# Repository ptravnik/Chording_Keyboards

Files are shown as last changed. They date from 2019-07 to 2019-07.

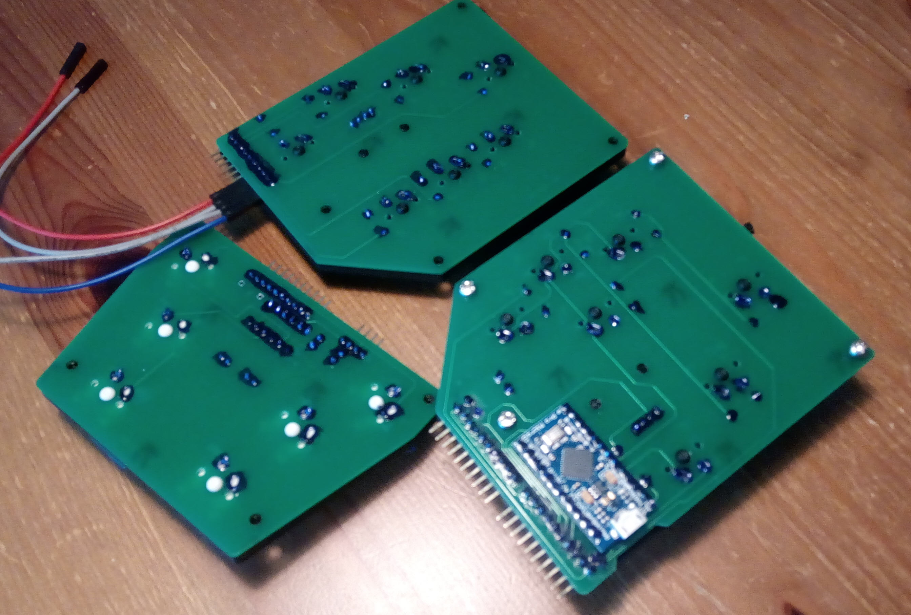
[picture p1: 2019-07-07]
Pictures/04_Soldering_Completed.jpg

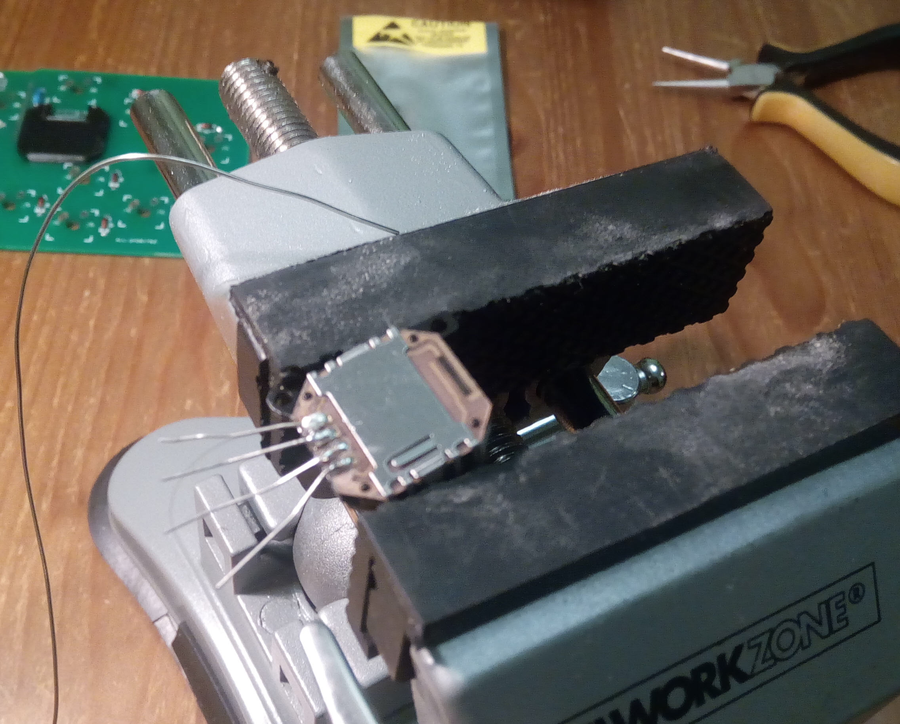
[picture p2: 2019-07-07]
Pictures/03_Soldering_PSP_Joystick.jpg

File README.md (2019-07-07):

This project contains files for K-Chord and other chording keyboards.

[1] Why chording?
Medics may disagree, but it seems that constantly bending fingers back and forth while touch-typing by the 10-finger method is the second reason (besides the poor posture) why people have carpal tunnel syndrome. In such sense, "ergonomic" keyboards help just a little if not at all. There are numerous mechanical keyboard on the market. Cherry switches and their clones offer performance superior to the film keyboards, but the idea is pretty much the same: 10 fingers, 60 or so switches; once in a while one must reach that switch in the galaxy far, far away with the left or right pinky!

The main drive for this project was not to type faster than speech, a a steno professionals do, but to type at reasonable speed whole day with no strain. In practice, I seldom exceed 20 WPM (just cannot think GOOD code that fast!), but can maintain this for many hours - without ever bending a finger. The keyboard has 8 finger buttons and 6 thumb buttons. The fingers always remain in the "home" position; there is nothing else, but the home position. The thumbs move as the nature intended: in the main (grip) joint, with the zero second joint bending. By shifting the fingers down 1 inch, a set of two analog joysticks, three mouse buttons and 4 arrow keys is accessible. Together with the left thumb, the arrow keys provide full set of cursor movements, including page-up and page-down.

This is the third version of my chording keyboard. The work in progress is described on the Hackaday site https://hackaday.io/project/25386-chording-hybrid-keyboard. The experience has been good so far. I use it now as my primary input method, for text writing, programming, and operating specialized software.

[2] Building a chording keyboard.
This project depository contains:

(a) the full electronics description as a set of three PCBs,

(b) A set of CNC files for making a body, and

(c) the code for Arduino Micro, which drives the entire project. No modification is required at the operating system side; the keyboard works as an off-the-shelf USB keyboard. It has been tested on Windows and Linux extensively.

To order PCBs, simply use Gerber files provided or modify KiCAD files to you liking. The body can be machined on a CNC router (recommeneded), 3-D printed or laser-cut (some compromizes on the shape). To build the firmware, copy the .ino folder and use Arduino IDE to compile and upload (put any macros of your liking into the macros.h file).

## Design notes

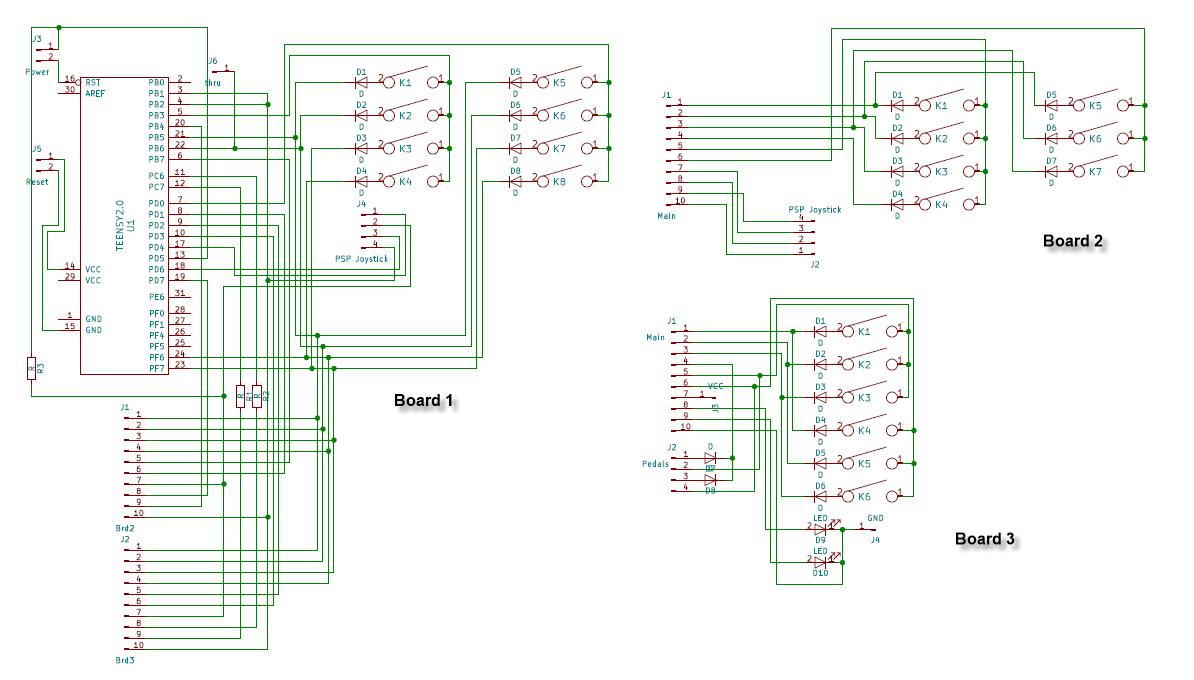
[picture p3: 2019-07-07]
Pictures/Schematics.png

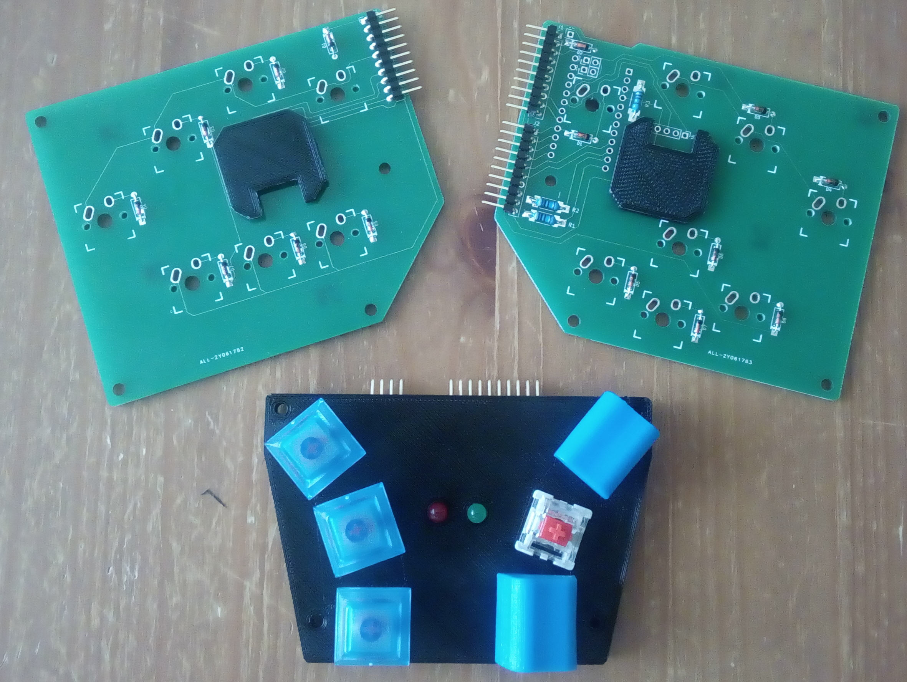
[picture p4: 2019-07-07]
Pictures/02_Stands_for_Joysticks.jpg

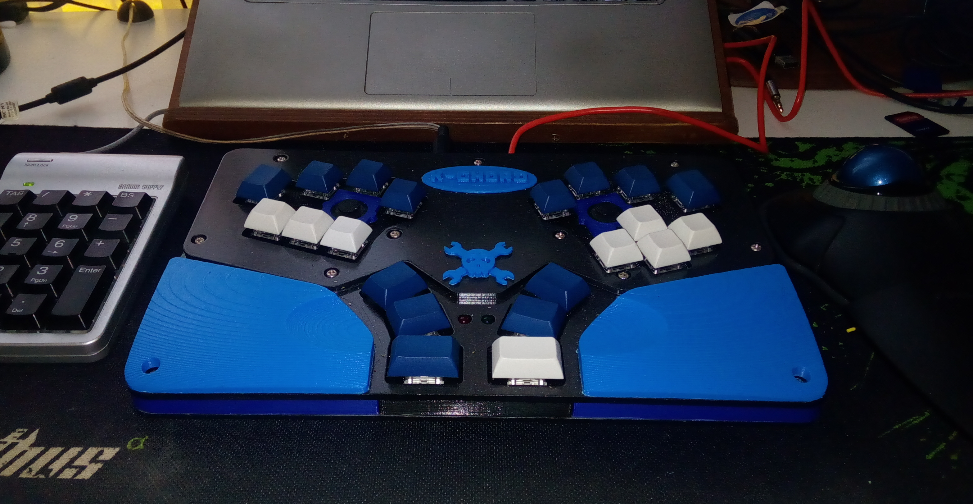
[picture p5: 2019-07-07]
Pictures/08_Keyboard_Completed.jpg

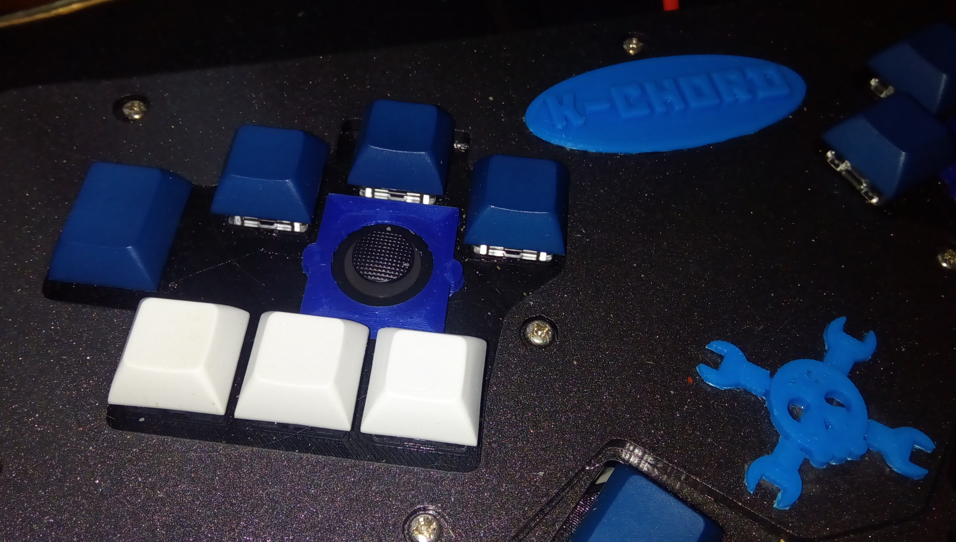
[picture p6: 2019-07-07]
Pictures/09_Left_Hand.jpg

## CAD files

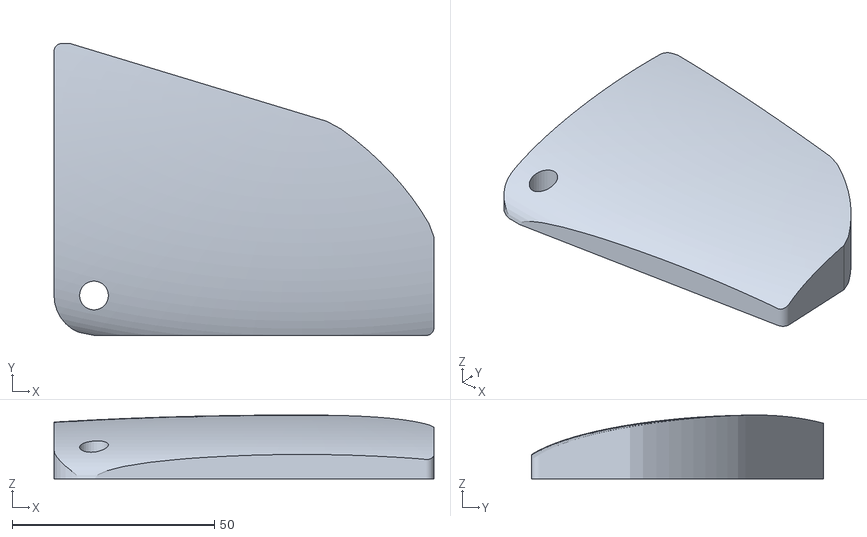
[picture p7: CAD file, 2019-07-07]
stls/Wrist_L.stl
94.1 x 72.3 x 15.8

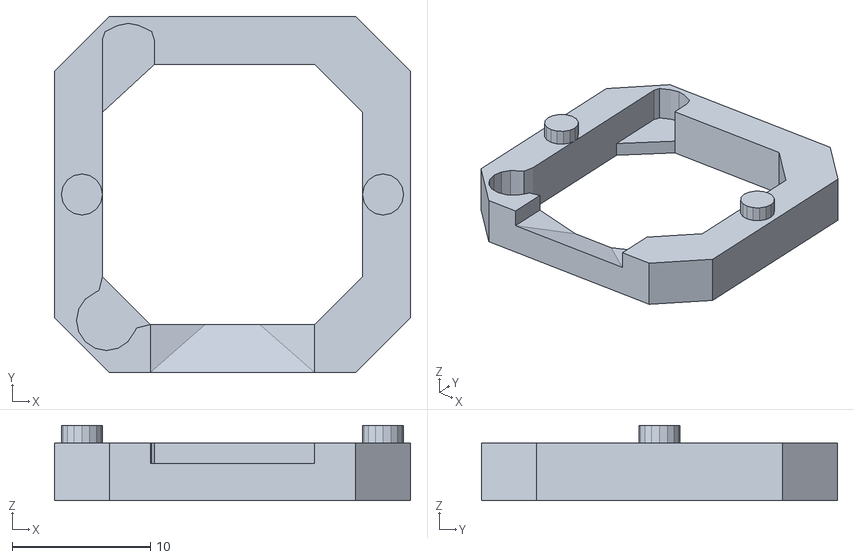
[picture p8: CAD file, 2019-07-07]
stls/Joystick_Holder.stl
25.7 x 25.7 x 5.45

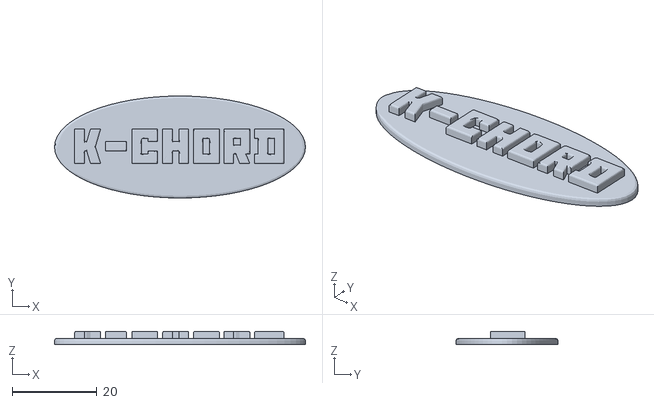
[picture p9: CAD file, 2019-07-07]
stls/K_Chord_Logo.stl
59.4 x 24.1 x 3.17

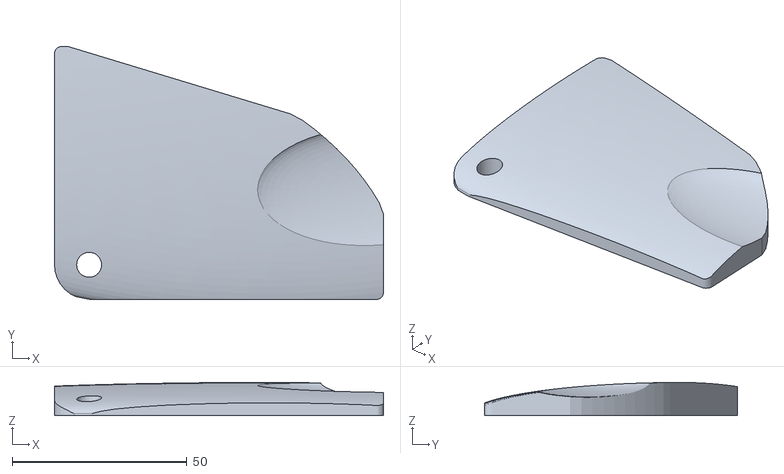
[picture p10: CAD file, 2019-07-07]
stls/Wrist_L_Low.stl
94.1 x 72.3 x 9.49

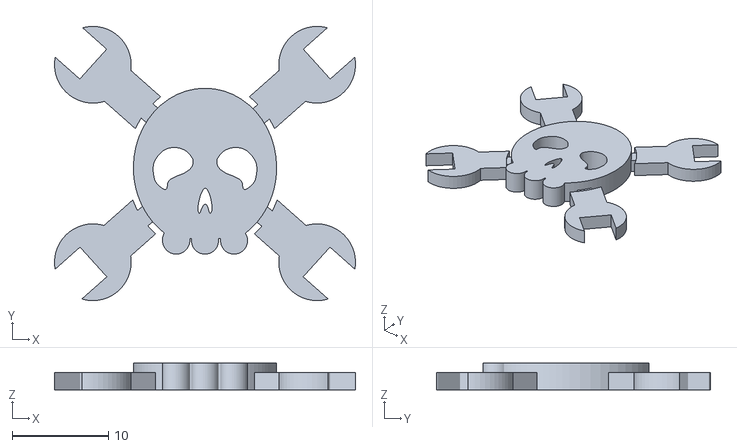
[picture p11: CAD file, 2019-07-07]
stls/Hackaday_Logo.stl
31.3 x 28.5 x 2.77

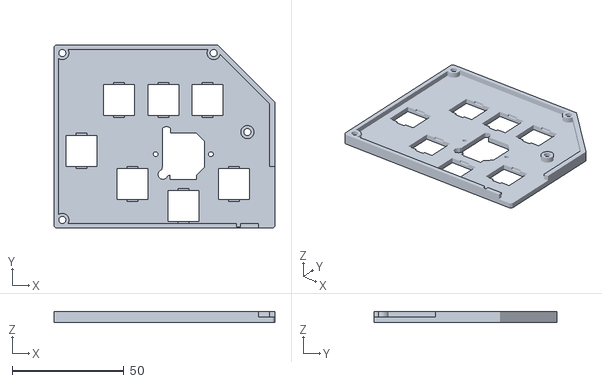
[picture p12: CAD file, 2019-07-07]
stls/Sabot_2.stl
99.0 x 82.2 x 4.95

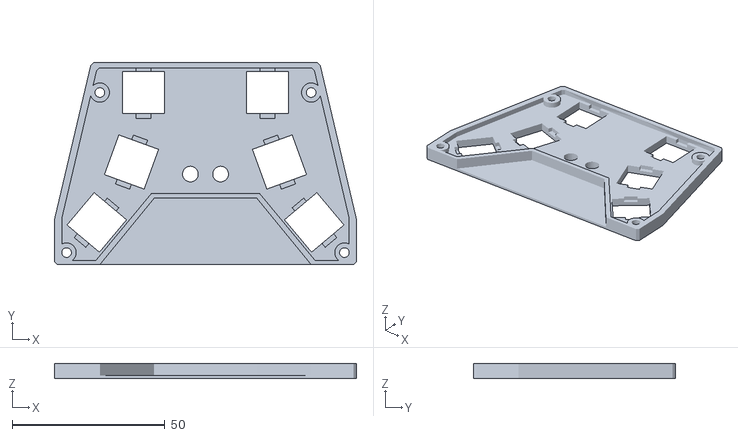
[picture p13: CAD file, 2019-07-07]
stls/Sabot_3.stl
99.0 x 66.3 x 4.95

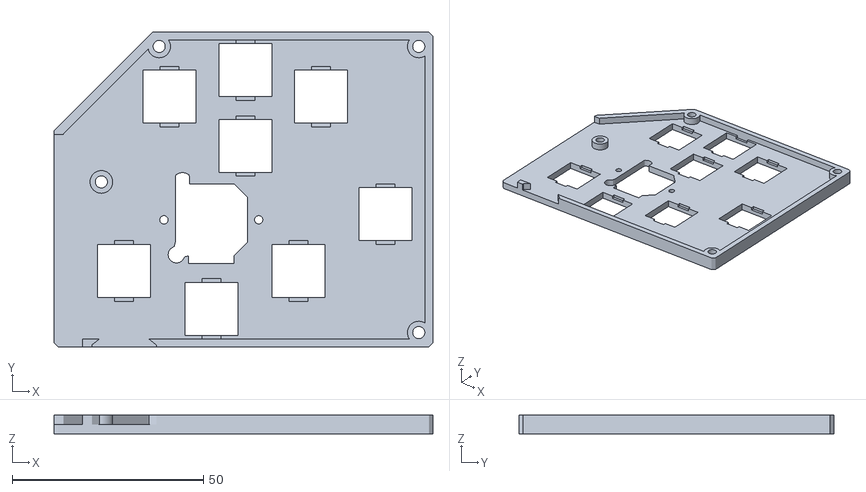
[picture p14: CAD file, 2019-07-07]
stls/Sabot_1.stl
99.0 x 82.2 x 4.95

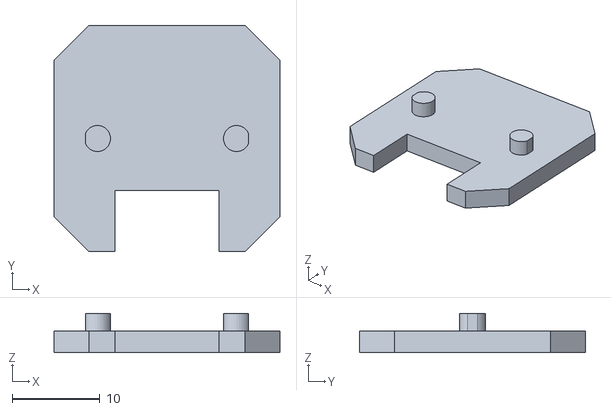
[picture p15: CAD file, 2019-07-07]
stls/Joystick_Stand.stl
25.7 x 25.7 x 4.46

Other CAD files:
stls/Wrist_R_Low.stl
stls/Wrist_R.stl

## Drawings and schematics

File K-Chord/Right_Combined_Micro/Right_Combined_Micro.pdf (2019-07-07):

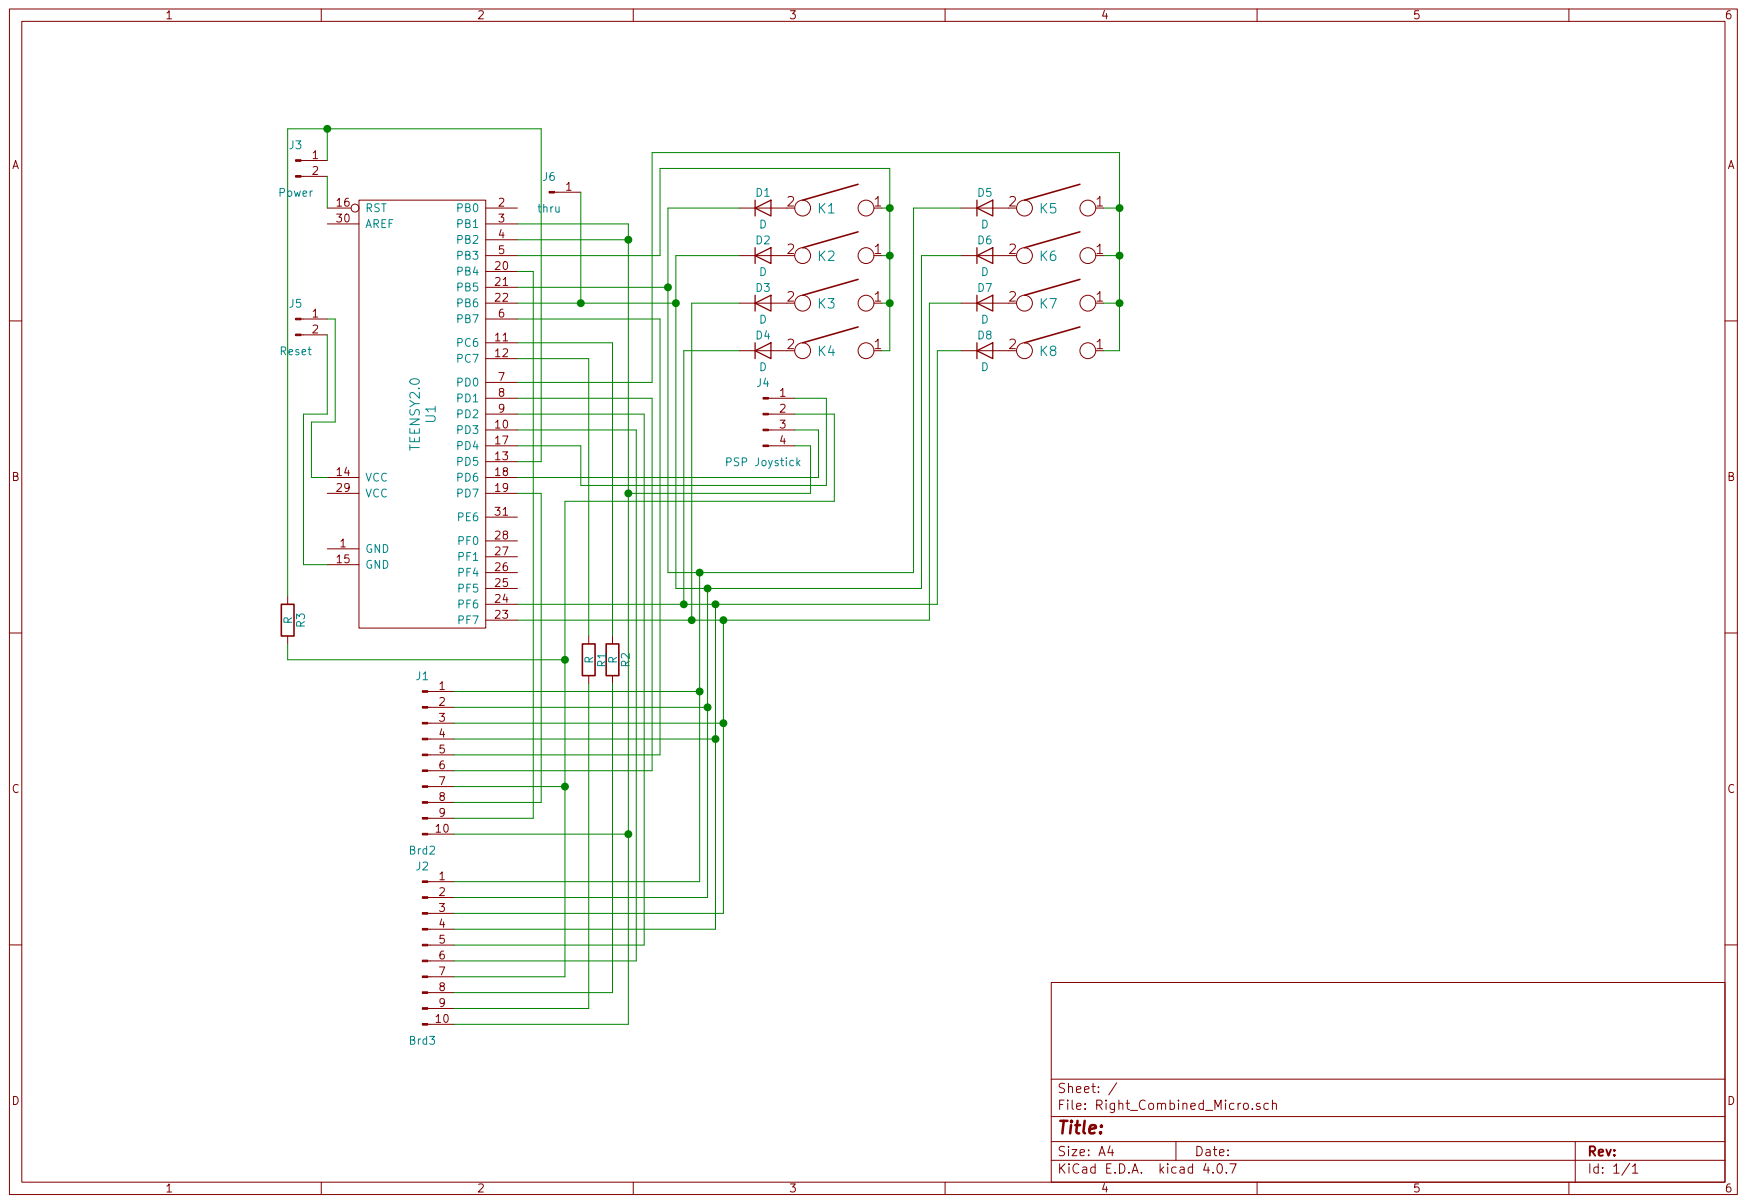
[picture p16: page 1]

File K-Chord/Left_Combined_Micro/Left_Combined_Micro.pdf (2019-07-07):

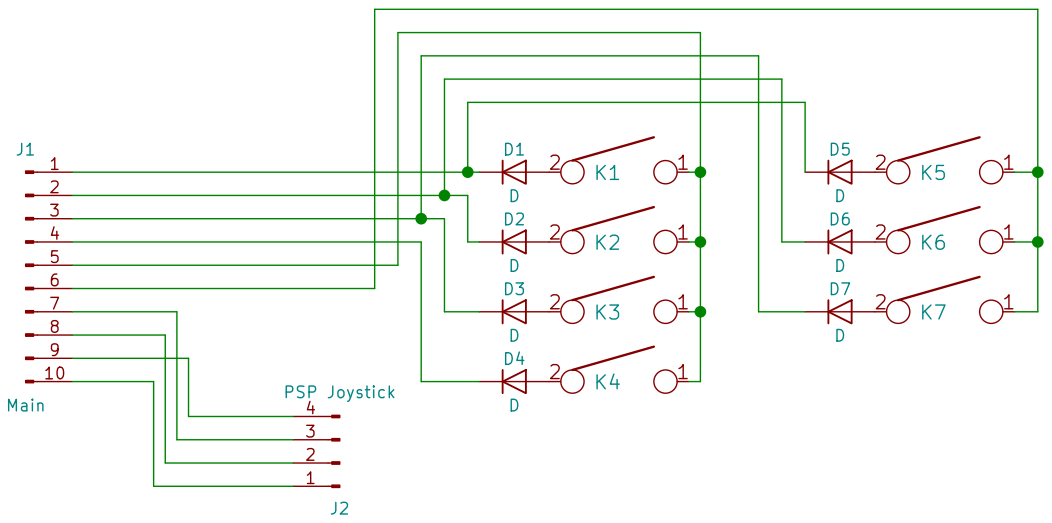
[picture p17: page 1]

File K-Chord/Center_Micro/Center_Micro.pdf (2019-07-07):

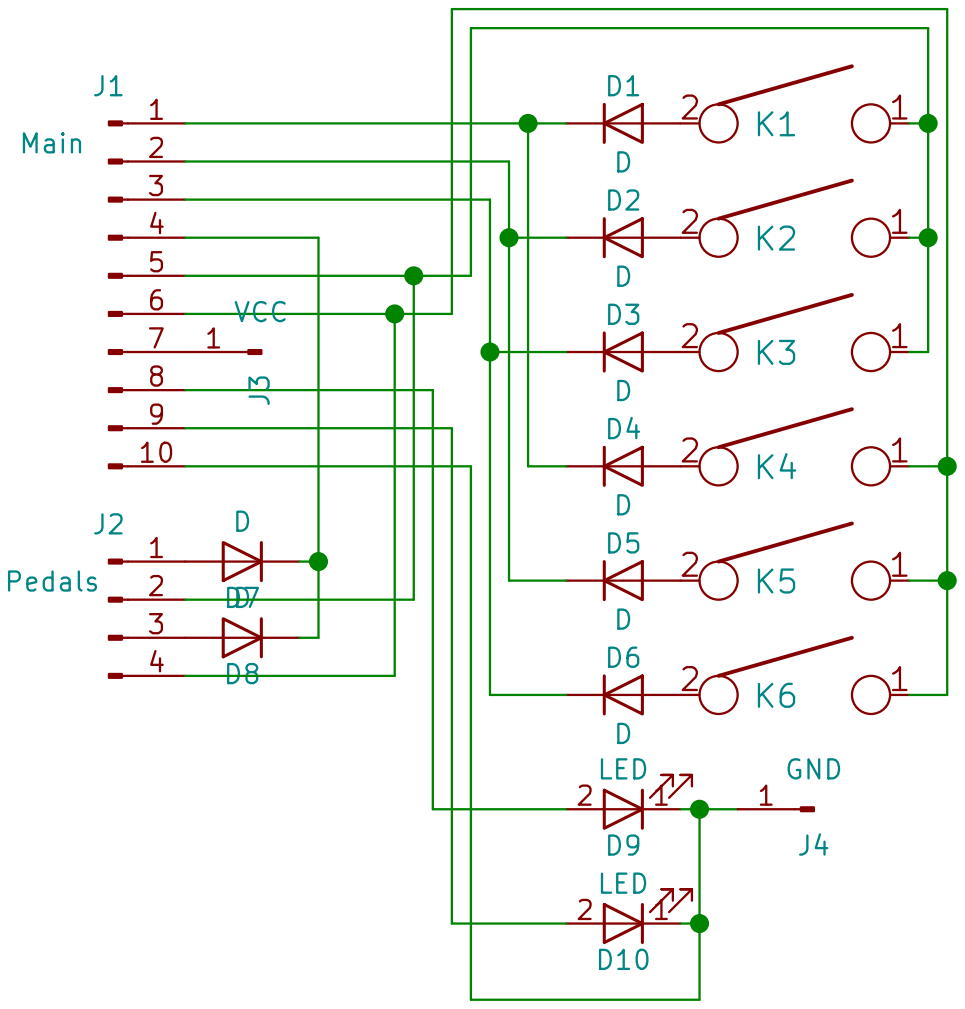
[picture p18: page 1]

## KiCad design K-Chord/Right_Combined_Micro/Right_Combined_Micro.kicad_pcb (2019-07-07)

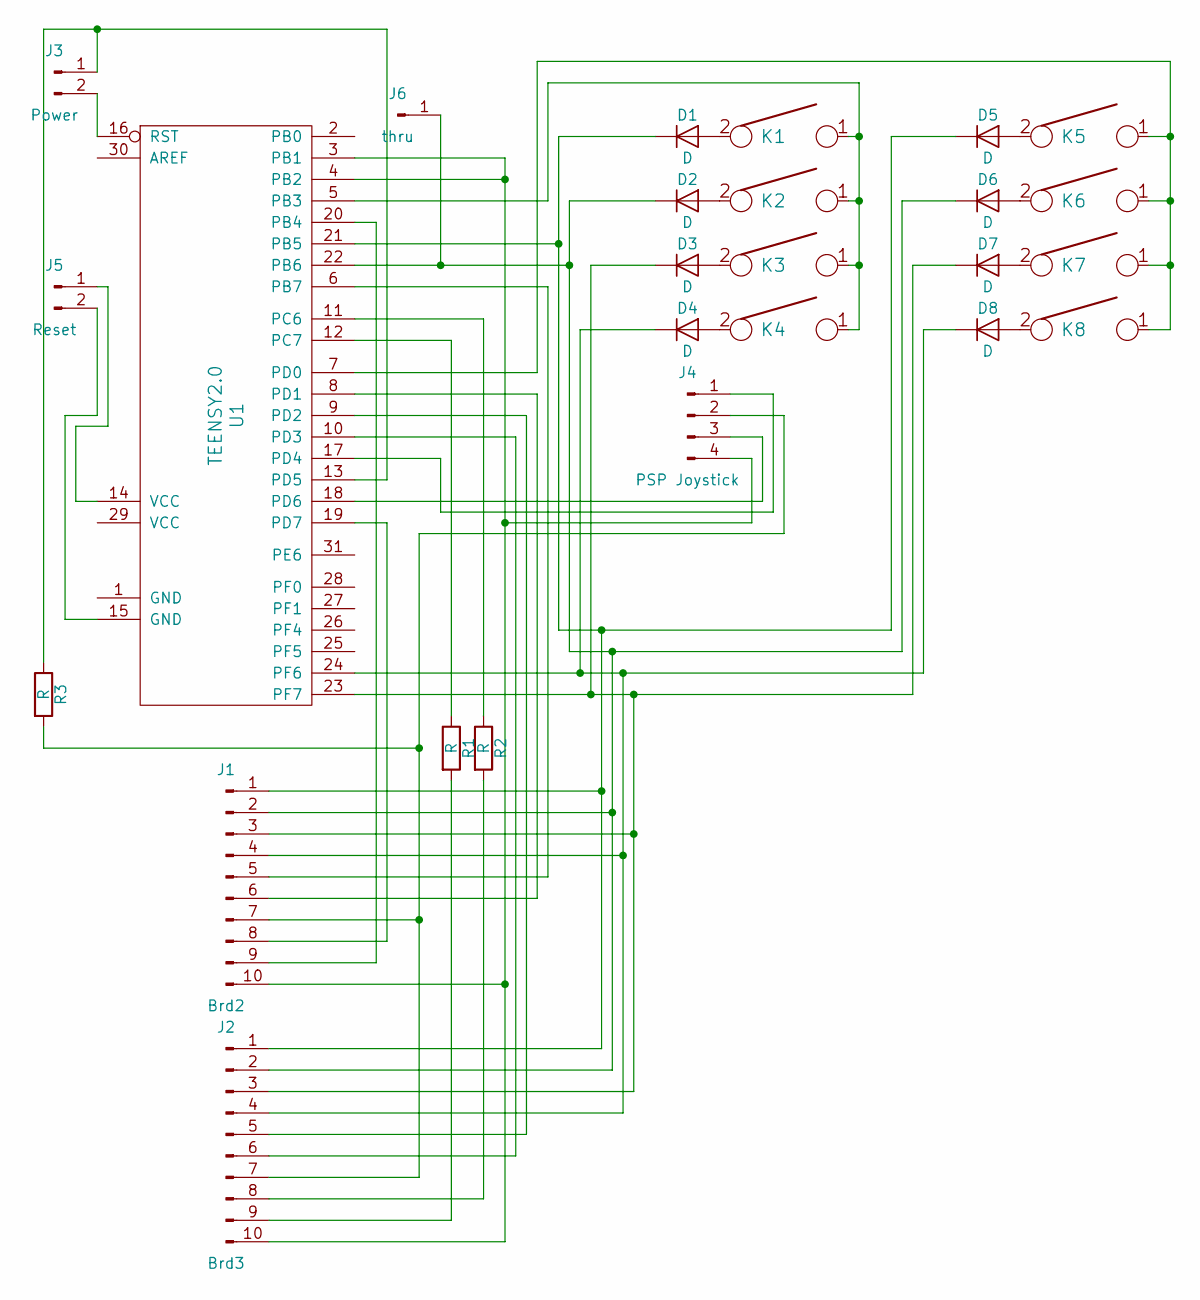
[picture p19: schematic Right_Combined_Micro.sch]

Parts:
D1, D2, D3, D4, D5, D6, D7, D8: D; D_SOD123_axial
J1: Brd2; Pin_Header_Straight_1x10_Pitch2.54mm
J2: Brd3; Pin_Header_Straight_1x10_Pitch2.54mm
J3: Power; Pin_Header_Straight_1x02_Pitch2.54mm
J4: PSP Joystick; Pin_Header_Straight_1x04_Pitch2.54mm
J5: Reset; Pin_Header_Straight_1x02_Pitch2.54mm
J6: thru; Pin_Header_Straight_1x01_Pitch2.54mm
K1, K2, K3, K4, K5, K6, K7, K8: KEYSW; Mx_Alps_100
R1, R2, R3: R; Resistor_SMD+THTuniversal_2512_RM10_HandSoldering
U1: TEENSY2.0; Pro_Micro

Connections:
unnamed: D1.1 (K), D5.1 (K), J1.1, J2.1, U1.21 (PB5)
unnamed: D1.2 (A), K1.2
unnamed: D2.1 (K), D6.1 (K), J1.2, J2.2, J6.1, U1.22 (PB6)
unnamed: D2.2 (A), K2.2
unnamed: D3.1 (K), D7.1 (K), J1.3, J2.3, U1.23 (PF7)
unnamed: D3.2 (A), K3.2
unnamed: D4.1 (K), D8.1 (K), J1.4, J2.4, U1.24 (PF6)
unnamed: D4.2 (A), K4.2
unnamed: D5.2 (A), K5.2
unnamed: D6.2 (A), K6.2
unnamed: D7.2 (A), K7.2
unnamed: D8.2 (A), K8.2
unnamed: J1.5, U1.6 (PB7)
unnamed: J1.6, U1.8 (PD1)
unnamed: J1.7, J2.7, J4.2, R3.2
unnamed: J1.8, U1.19 (PD7)
unnamed: J1.9, U1.20 (PB4)
unnamed: J1.10, J2.10, J4.4, U1.3 (PB1), U1.4 (PB2)
unnamed: J2.5, U1.9 (PD2)
unnamed: J2.6, U1.10 (PD3)
unnamed: J2.8, R2.2
unnamed: J2.9, R1.2
unnamed: J3.1, R3.1, U1.13 (PD5)
unnamed: J3.2, U1.16 (RST)
unnamed: J4.1, U1.17 (PD4)
unnamed: J4.3, U1.18 (PD6)
unnamed: J5.1, U1.14 (VCC)
unnamed: J5.2, U1.15 (GND)
unnamed: K1.1, K2.1, K3.1, K4.1, U1.5 (PB3)
unnamed: K5.1, K6.1, K7.1, K8.1, U1.7 (PD0)
unnamed: R1.1, U1.12 (PC7)
unnamed: R2.1, U1.11 (PC6)

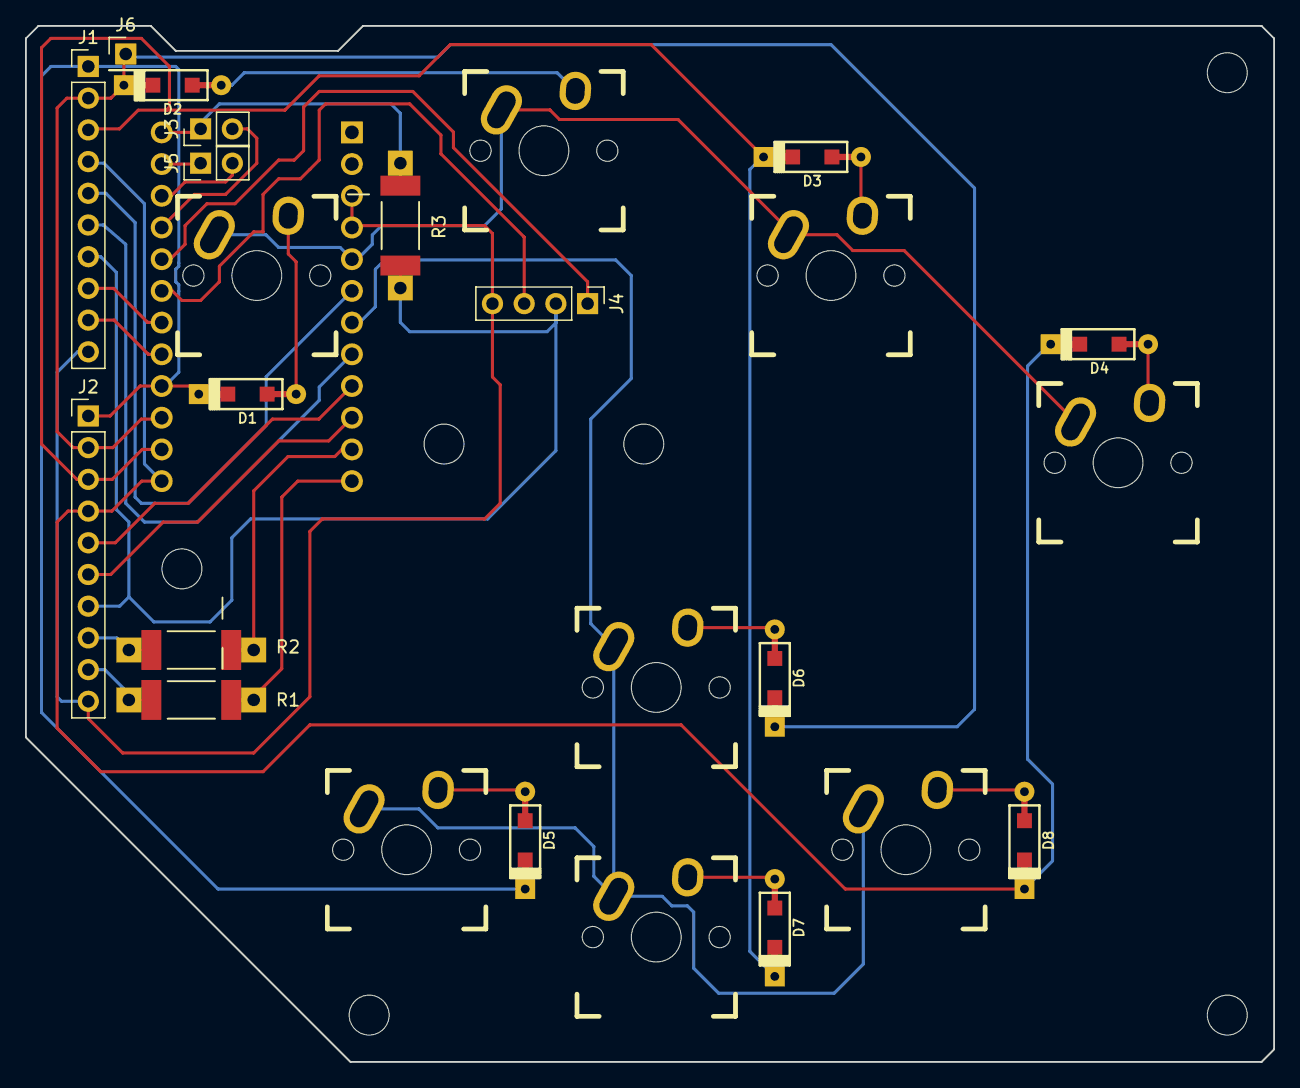
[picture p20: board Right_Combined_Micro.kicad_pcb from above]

Board: 2 copper layers, 100.0 x 83.0 mm, 26 parts (1 on the bottom side), 32 nets.

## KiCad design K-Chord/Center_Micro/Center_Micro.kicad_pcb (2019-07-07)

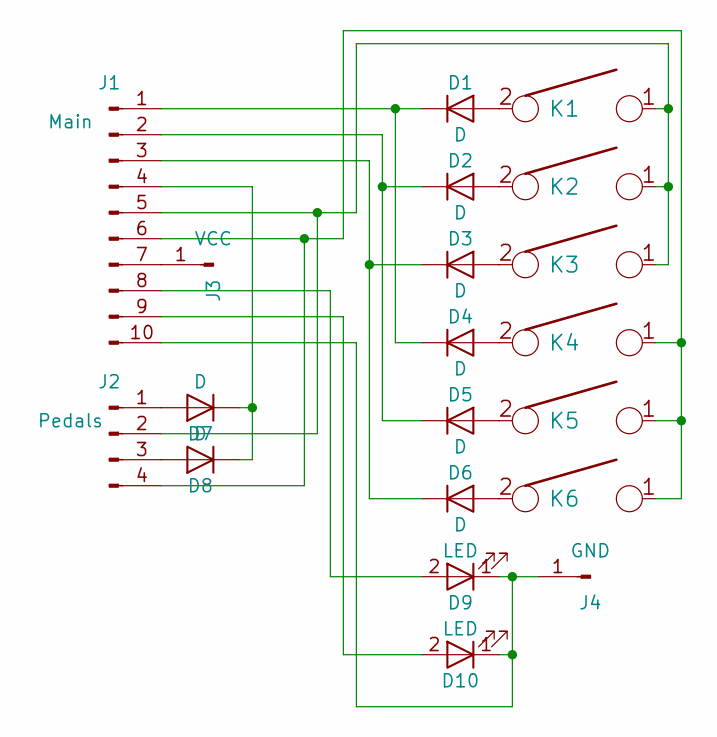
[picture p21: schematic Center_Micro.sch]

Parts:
D1, D2, D3, D4, D5, D6, D7, D8: D; D_SOD123_axial
D9, D10: LED; LED_TH
J1: Main; Pin_Header_Angled_1x10_Pitch2.54mm
J2: Pedals; Pin_Header_Angled_1x04_Pitch2.54mm
J3: VCC; Pin_Header_Straight_1x01_Pitch2.54mm
J4: GND; Pin_Header_Straight_1x01_Pitch2.54mm
K1, K2, K3, K4, K5, K6: KEYSW; Mx_Alps_100

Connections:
unnamed: D1.1 (K), D4.1 (K), J1.1
unnamed: D1.2 (A), K1.2
unnamed: D2.1 (K), D5.1 (K), J1.2
unnamed: D2.2 (A), K2.2
unnamed: D3.1 (K), D6.1 (K), J1.3
unnamed: D3.2 (A), K3.2
unnamed: D4.2 (A), K4.2
unnamed: D5.2 (A), K5.2
unnamed: D6.2 (A), K6.2
unnamed: D7.1 (K), D8.1 (K), J1.4
unnamed: D7.2 (A), J2.1
unnamed: D8.2 (A), J2.3
unnamed: D9.2 (A), J1.8
unnamed: D9.1 (K), D10.1 (K), J1.10, J4.1
unnamed: D10.2 (A), J1.9
unnamed: J1.5, J2.2, K1.1, K2.1, K3.1
unnamed: J1.6, J2.4, K4.1, K5.1, K6.1
unnamed: J1.7, J3.1

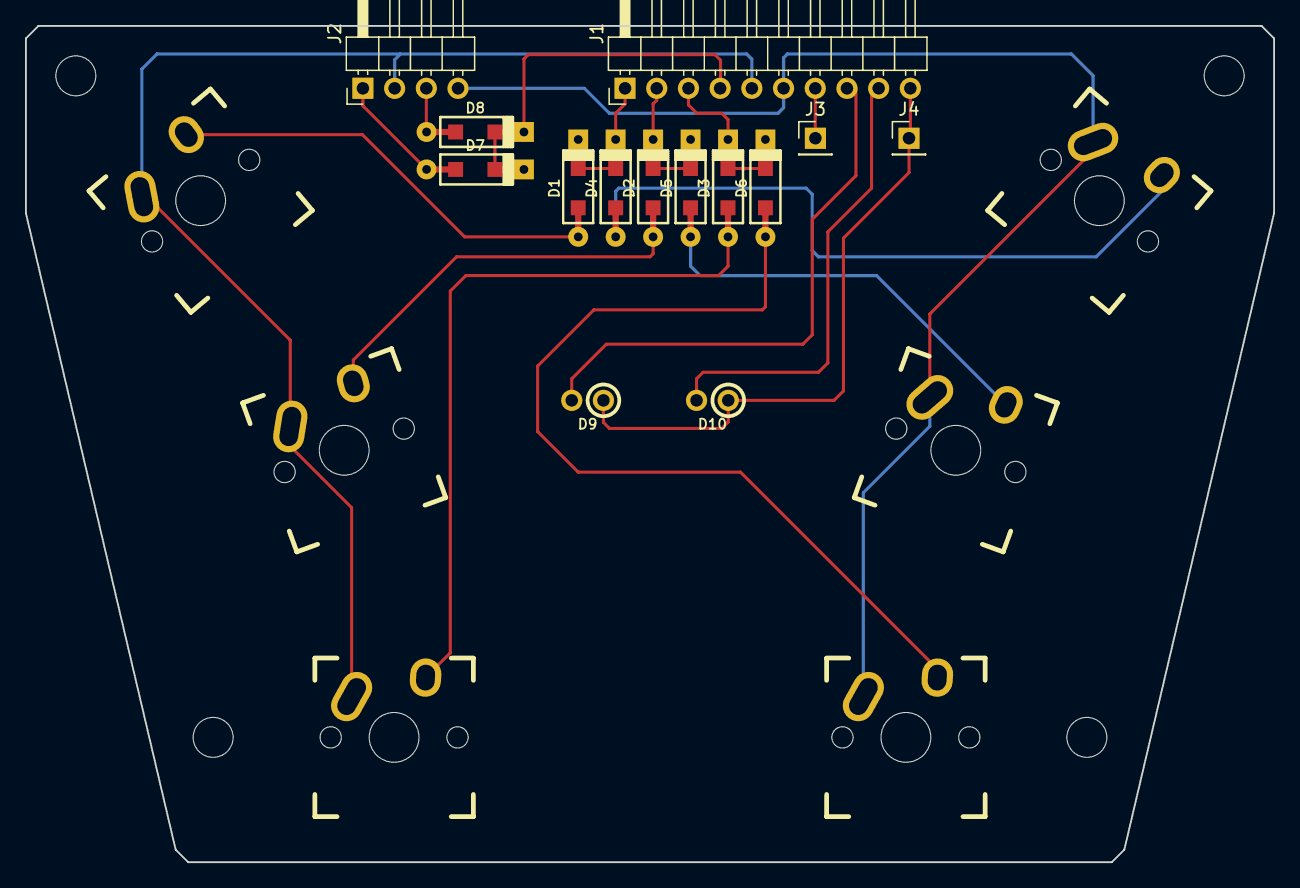
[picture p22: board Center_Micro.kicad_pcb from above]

Board: 2 copper layers, 100.0 x 67.0 mm, 20 parts (0 on the bottom side), 18 nets.

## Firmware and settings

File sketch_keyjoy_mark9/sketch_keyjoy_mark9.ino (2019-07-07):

//
// 21-button input method for stationary chorded keyboard with 2 PSP joysticks
// Left hand: 4 finger buttons and 3 mouse buttons
// Right hand: 4 finger buttons and 4 arrow buttons
// Left thumb: BACK, Shift, Control
// Right thumb: SPACE, Function, Alt
// v 9.0 04-Jul-2019
// Tested with Arduino IDE 1.8.9
// Set the board to Arduiono/Genuino Micro
// This work is public domain under GNU licence
//

// Uncomment for serial debugging
//#define _DEBUG
//#define _DEBUG_MOUSE
//#define _DEBUG_KEYBOARD

// Uncomment to disable hardware while debugging
//#define _DISABLE_MOUSE
//#define _DISABLE_KEYBOARD

#include <Keyboard.h>
#include <Mouse.h>
#include "keys.h"
#include "macros.h"
#include "keyjoy.h"

//
// Setup code here, to run once:
//
void setup()
{
  #ifdef _DEBUG
  Serial.begin(9600);
  #endif

  for ( int i = 0; i < 2; i++)
  {
    pinMode(LEDPins[i], OUTPUT);
    digitalWrite(LEDPins[i], HIGH);
  }

  Calibrate_Pots();

  for ( int i = 0; i < 4; i++)
  {
    pinMode(readPins[i], INPUT_PULLUP);
  }
  for ( int i = 0; i < 6; i++)
  {
    pinMode(writePins[i], OUTPUT);
    digitalWrite(writePins[i], HIGH);
  }

  Read_Arrow_Buttons();
  keyboardActive = (arrow_buttons[0] + arrow_buttons[1] + arrow_buttons[2] + arrow_buttons[3]) == 0;

  if ( !keyboardActive) return;
  Mouse.begin();
  Keyboard.begin();
  delay( 500);
  SetLEDs();
  return;  
}

//
// runs continuously
//
void loop()
{
  int lCombo;
  int rCombo;
  bool ProcessFurther;
  if ( keyboardActive)
  {
    Read_Bottom_Buttons();
    Read_Mouse_Buttons();
    Read_Arrow_Buttons();
    Read_Top_Buttons();
    Read_Mouse_Pots();
    if( (left[2] == 0) && (right[2] == 0) && ((left[3] > 0) || (right[3] > 0)))
    {
      #ifdef _DEBUG_KEYBOARD
      Serial.print( repeatKeyMode);
      Serial.print( "_");
      Serial.print( left[1]);
      Serial.print( "_");
      Serial.println( right[1]);
      #endif
      if( (!repeatKeyMode) && DecodeTwoHanded())
      {
        lCombo = left[1];
        if( right[1] == 16) lCombo += 32;
        if( funMode>0) lCombo += 64;
        rCombo = right[1];
        if( left[1] == 16) rCombo += 32;
        if( funMode>0) rCombo += 64;
        DecodeButtons( lCombo, leftMapping);
        DecodeButtons( rCombo, rightMapping);
      }
      for( int i=0; i<4; i++)
      {
        left[i] = 0;
        right[i] = 0;
      }
      repeatKeyMode = false;
    }
    if( ((left[1] == 16) || (left[2] >= 2)) && (right[2] == 0) && (right[3] > 0))
    {
      rCombo = right[1];
      if( left[1] == 16) rCombo += 32;
      if( DecodeTwoHanded()) DecodeButtons( rCombo, rightMapping);
      for( int i=0; i<4; i++) right[i] = 0;
      repeatKeyMode = true;
    }
    if( ((right[1] == 16) || (right[2] >= 2)) && (left[2] == 0) && (left[3] > 0))
    {
      lCombo = left[1];
      if( right[1] == 16) lCombo += 32;
      if( DecodeTwoHanded()) DecodeButtons( lCombo, leftMapping);
      for( int i=0; i<4; i++) left[i] = 0;
      repeatKeyMode = true;
    }
  }
  SetLEDs();
  #ifdef _DEBUG
  delay(500);
  #else
  // Eliminate unwanted Tx, Rx lights
  RXLED1;
  TXLED1;
  delay(5);
  #endif
  return;
}

//
// Calibrates middle points in all 4 pots, only needs to run once
//
void Calibrate_Pots()
{
  int pin, data;
  for( int i=0; i<4; i++)
  {
    pin = pot_sensorPins[i];
    data = analogRead(pin);
    for( int i=0; i<4; i++)
    {
      delay(10);
      data += analogRead(pin);
    }
    pot_Middle[i] = data/5;
    pot_Position[i] = _NULLMOUSE;
  }
  return;
}

//
// Reads the pots and sends mouse movement commands
//
void Read_Mouse_Pots()
{
  int pin, data;

  #ifndef _DEBUG
  // mouse pot reading is decimated, so the mouse is not too fast
  if( mouse_Counter != 0)
  {
    mouse_Counter++;
    if( mouse_Counter >= _MOUSE_DECIMATOR) mouse_Counter = 0;
    return;
  }
  mouse_Counter++;
  #endif

  for( int i=0; i<4; i++)
  {
    pin = pot_sensorPins[i];
    data = analogRead(pin);
    delay(3);
    data += analogRead(pin);
    data /= 2;
    NormalizeJoystickBallistic( i, data);
  }

  //
  // Normalize left joystick to -1 to 1 (scrolling speed too fast anyway)
  //
  NormalizeJoystickToOne( 2);
  NormalizeJoystickToOne( 3);

  if( fun_Pressed)
  {
    if( pot_Position[2] != 0)
    {
      if( shiftMode == 0) Keyboard_press( _SHIFT);
      Mouse_scroll( pot_Position[2], _SCROLL_DELAY1);
      if( shiftMode == 0) Keyboard_release( _SHIFT);
      funMode = 0;
    }
    if( pot_Position[3] != 0)
    {
      if( !control_Pressed) Keyboard_press( _CTRL);
      Mouse_scroll( pot_Position[3], _SCROLL_DELAY1);
      if( !control_Pressed) Keyboard_release( _CTRL);
      funMode = 0;
    }
    if( pot_Position[0] != 0 || pot_Position[1] != 0)
    {
      NormalizeJoystickToOne( 0);
      NormalizeJoystickToOne( 1);
      Mouse_move(pot_Position[0], pot_Position[1]);
      funMode = 0;
    }
  }
  else
  {
    if( pot_Position[2] != 0)
    {
      if( funMode >= 1) Mouse_scroll( pot_Position[2], _SCROLL_DELAY4);
      else Mouse_scroll( pot_Position[2], _SCROLL_DELAY1);
    }
    else
    {
      Mouse_move(pot_Position[0], pot_Position[1]);
    }
  }

  #ifdef _DEBUG_MOUSE
  Serial.print( "Mouse pointer: ");
  Serial.print( pot_Position[0])
  Serial.print(" ");
  Serial.print( pot_Position[1])
  Serial.print(" ");
  Serial.print( pot_Position[2])
  Serial.print(" ");
  Serial.println( pot_Position[3])
  #endif
  return;
}

//
// Reads 3 mouse buttons using read lines 0,1,2 and write line 3
//
void Read_Mouse_Buttons()
{
  digitalWrite( writePins[1], LOW);
  button_L = ReadPinLogical( 0);
  button_R = ReadPinLogical( 1);
  button_M = ReadPinLogical( 2);
  digitalWrite( writePins[1], HIGH);
  Mouse_set( button_L, MOUSE_LEFT);
  Mouse_set( button_R, MOUSE_RIGHT);
  Mouse_set( button_M, MOUSE_MIDDLE);
  #ifdef _DEBUG_MOUSE
  Serial.print( "Mouse buttons: ");
  Serial.print( String(button_L, DEC));
  Serial.print( String(button_M, DEC));
  Serial.println( String(button_R, DEC));
  #endif
  return;
}

//
// Reads 4 arrow buttons using read lines 0,1,2,3 and write line 1
//
void Read_Arrow_Buttons()
{
  bool button;
  digitalWrite( writePins[3], LOW);
  for( int i=0; i<4; i++)
  {
    button = ReadPinLogical( i);
    if( !button && arrow_buttons[i] != 0)
    {
      Keyboard_release( arrow_buttons[i]);
      arrow_buttons[i] = _CH0;
    }
    if( !space_L_Pressed && button && arrow_buttons[i] != arrowMap_0[i])
    {
      space_L_Consumed = false;
      if( arrow_buttons[i] != 0) Keyboard_release( arrow_buttons[i]);
      Keyboard_press( arrowMap_0[i]);
      arrow_buttons[i] = arrowMap_0[i];
    }
    if( space_L_Pressed && button && arrow_buttons[i] != arrowMap_1[i])
    {
      space_L_Consumed = true;
      if( arrow_buttons[i] != 0) Keyboard_release( arrow_buttons[i]);
      Keyboard_press( arrowMap_1[i]);
      arrow_buttons[i] = arrowMap_1[i];
    }
  }
  digitalWrite( writePins[3], HIGH);
  return;
}

//
// Reads bottom 6 buttons and pedals using control lines 4,5 and data lines 1,2,3,4
// Sends shift, alt, control, sets function and space
//
void Read_Bottom_Buttons()
{
  long t = millis();
  digitalWrite(writePins[4], LOW);
  for( int i=0; i<4; i++) bottom[i] = ReadPinLogical( i); 
  digitalWrite(writePins[4], HIGH);
  digitalWrite(writePins[5], LOW);
  for( int i=4; i<8; i++) bottom[i] = ReadPinLogical( i-4); 
  digitalWrite(writePins[5], HIGH);
  Set_Spaces();
  Set_Shift_Mode( t);
  Set_Control_Mode();
  Set_Function_Mode( t);
  Set_Alt_Mode();
  Set_Pedals();
}

//
// Sets Both Space buttons
//
void Set_Spaces()
{ 
  space_L_Pressed = bottom[0];
  space_R_Pressed = bottom[4];
}

//
// Sets Shift mode button
//
void Set_Shift_Mode(long t)
{
  if ( bottom[1] && !shift_Pressed)
  {    
    shift_Pressed = true;
    switch( shiftMode)
    {
      case 1:
        if( t-shift_Pressed_Time < _BLINK_PERIOD) shiftMode = 2;
        else shiftMode = 0;
        break;
      default:
        shiftMode++;
        if( shiftMode>2) shiftMode = 0;
        break;  
    }
    shift_Pressed_Time = t;
    if( shiftMode>0) Keyboard_press(_SHIFT);
    else Keyboard_release(_SHIFT);
    #ifdef _DEBUG_KEYBOARD
    Serial.print( "ShiftMode = ");
    Serial.println( shiftMode);
    #endif
  }
  if ( !bottom[1] && shift_Pressed)
  {
    shift_Pressed = false;
    if( shiftMode == 1 && t-shift_Pressed_Time > _SHIFT_RELEASE_TIME)
    {
      shiftMode = 0;
      Keyboard_release( _SHIFT);
    }
  }
}

//
// Sets Function mode button
//
void Set_Function_Mode(long t)
{
  if ( bottom[5] && !fun_Pressed)
  {
    fun_Pressed = true;
    switch( funMode)
    {
      case 1:
        if( t-fun_Pressed_Time < _BLINK_PERIOD) funMode = 2;
        else funMode = 0;
        break;
      default:
        funMode++;
        if( funMode>2) funMode = 0;
        break;
    }
    fun_Pressed_Time = t;
    #ifdef _DEBUG_KEYBOARD
    Serial.print( "FunMode = ");
    Serial.println( funMode);
    #endif
  }
  if ( !bottom[5] && fun_Pressed)
  {
    fun_Pressed = false;
    if( funMode == 1 && t-fun_Pressed_Time > _SHIFT_RELEASE_TIME)
    {
      funMode = 0;
    }
  }
}

//
// Sets Control mode button
//
void Set_Control_Mode()
{
  if ( bottom[2] && !control_Pressed)
  {
    control_Pressed = true;
    Keyboard_press(_CTRL_R);
    #ifdef _DEBUG_KEYBOARD
    Serial.println( "Control pressed");
    #endif
  }
  if ( !bottom[2] && control_Pressed)
  {
    control_Pressed = false;
    Keyboard_release(_CTRL_R);
    #ifdef _DEBUG_KEYBOARD
    Serial.println( "Control released");
    #endif
  }
}

//
// Sets Alt mode button
//
void Set_Alt_Mode()
{
  if ( bottom[6] && !alt_Pressed)
  {
    alt_Pressed = true;
    Keyboard_press(_ALT);
    #ifdef _DEBUG_KEYBOARD
    Serial.println( "Alt pressed");
    #endif
  }
  if ( !bottom[6] && alt_Pressed)
  {
    alt_Pressed = false;
    Keyboard_release(_ALT);
    #ifdef _DEBUG_KEYBOARD
    Serial.println( "Alt released");
    #endif
  }
}

//
// Sets Pedals
//
void Set_Pedals()
{
  if( bottom[3] && !pedal_L_Pressed)
  {
    pedal_L_Pressed = true;
  }
  if( !bottom[3] && pedal_L_Pressed)
  {
    pedal_L_Pressed = false;
    SendRusLat();
  }
  if( bottom[7] && !pedal_R_Pressed)
  {
    pedal_R_Pressed = true;
    special_Requested = !special_Requested;
  }
  if( !bottom[7] && pedal_R_Pressed)
  {
    pedal_R_Pressed = false;
  }
}

//
// Reads top 8 buttons using control lines 0 and 1 and data lines 0,1,2,3
// Adds the Space buttons using data lines 2, 3, while control sinks to 1
//
void Read_Top_Buttons()
{
    left[0] = 0;
    right[0] = 0;
    left[2] = 0;
    right[2] = 0;
    int mult = 1;
    int b;

    // Left half
    digitalWrite(writePins[0], LOW);
    for( int i=0; i<4; i++)
    {
      b = ReadPin( i);
      left[0] += mult * b;
      left[2] += b;
      mult *= 2;
    }
    digitalWrite(writePins[0], HIGH);
    if( space_L_Pressed)
    {
      left[0] += 16;
      left[2] += 1;
    }
    if ( left[2] >= left[3])
    {
      left[1] = left[0];
      left[3] = left[2];    
    }

    // Right half
    mult = 1;
    digitalWrite(writePins[2], LOW);
    for( int i=0; i<4; i++)
    {
      b = ReadPin( i);
      right[0] += mult * b;
      right[2] += b;
      mult *= 2;
    }
    digitalWrite(writePins[2], HIGH);
    if( space_R_Pressed)
    {
      right[0] += 16;
      right[2] += 1;
    }
    if ( right[2] >= right[3])
    {
      right[1] = right[0];
      right[3] = right[2];    
    }
    #ifdef _DEBUG_KEYBOARD
    if( left[0]>0 || right[0] > 0)
    {
      Serial.print( "Top buttons: ");
      Serial.print( left[0]);
      Serial.print( ", ");
      Serial.println( right[0]);
    }
    #endif
    return;
}

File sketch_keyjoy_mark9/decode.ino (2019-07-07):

//
// Decodes all two-handed chords
// Returns true if further processing is requred
//
bool DecodeTwoHanded()
{
  // switch is used to speed up processing
  switch( left[1])
  {
    case 0:
      if( DecodeSpecialChord( 0, 1, "if()\n{\n}", "if :\n", "if", 2, 0)) return false;
      if( DecodeSpecialChord( 0, 4, "true", "True", "true", 0, 0)) return false;
      if( DecodeBaseChord(  0,16, ' ')) return false;
      if( DecodeStringChord( 0, 28, ";", 0, 1)) return false;
      return true;
    case 1:
      if( DecodeSpecialChord( 1, 0, "else\n{\n}", "else:\n", "else", 2, 0)) return false;
      if( DecodeSpecialChord( 1, 1, "for(int i=; i<= ; i++)\n{\n}", "for i in range( len()):\n", "for", 0, 0)) return false;
      if( DecodeSpecialChord( 1, 4, "do\n{\n}\nuntil( true)", "while True:\n\nif : break", "do", 0, 0)) return false;
      if( DecodeBaseChord( 1, 1, 'f')) return false;
      if( DecodeBaseChord( 1, 2, 'm')) return false;
      if( DecodeBaseChord( 1, 4, 'd')) return false;
      if( DecodeStringChord( 1, 5, "\"\"", 1, 0)) return false;
      if( DecodeStringChord( 1, 15, "ed", 0, 0)) return false;
      if( DecodeBaseChord( 1, 3, 'g')) return false;
      if( DecodeBaseChord( 1, 6, '-')) return false;
      if( DecodeBaseChord( 1, 7, '`')) return false;
      if( DecodeRussianChord( 1, 14, '>', '>')) return false;
      if( DecodeBaseChord( 1, 19, '7')) return false;
      return true;
    case 2:
      if( DecodeBaseChord( 2, 1, 'j')) return false;
      if( DecodeBaseChord( 2, 2, 'b')) return false;
      if( DecodeBaseChord( 2, 3, 'q')) return false;
      if( DecodeStringChord( 2, 5, "\'\'", 0, 0)) return false;
      if( DecodeBaseChord( 2, 6, '/')) return false;
      if( DecodeBaseChord( 2, 7, '\\')) return false;
      if( DecodeRussianChord( 2, 14, '<', '<')) return false;
      if( DecodeStringChord( 2, 15, "ad", 0, 0)) return false;
      if( DecodeBaseChord( 2, 19, '8')) return false;
      return true;
    case 3:
      if( DecodeSpecialChord( 3, 0, "try\n{\n}\ncatch( Exception ex)\n{\n}\nfinally\n{\n}", "try:\n\nexcept:", "try", 0, 0)) return false;
      if( DecodeSpecialChord( 3, 2, "while(true)\n{\n}", "while True:\n", "while", 0, 0)) return false;
      if( DecodeBaseChord( 3, 1, 'v')) return false;
      if( DecodeBaseChord( 3, 2, 'w')) return false;
      if( DecodeRussianChord( 3, 3, '"', '"')) return false;
      if( DecodeBaseChord( 3, 4, 'z')) return false;
      if( DecodeStringChord( 3, 6, "th", 0, 0)) return false;
      if( DecodeStringChord( 3, 14, "if ", 0, 0)) return false;
      if( DecodeStringChord( 3, 15, "un", 0, 0)) return false;
      return true;
    case 4:
      if( DecodeSpecialChord( 4, 0, "false", "False", "false", 0, 0)) return false;
      if( DecodeBaseChord( 4, 1, 'u')) return false;
      if( DecodeBaseChord( 4, 4, 'x')) return false;
      if( DecodeStringChord( 4, 5, "ly", 0, 0)) return false;
      if( DecodeBaseChord( 4, 6, '*')) return false;
      if( DecodeStringChord( 4, 14, "for", 0, 0)) return false;
      if( DecodeStringChord( 4, 15, "al", 0, 0)) return false;
      if( DecodeBaseChord( 4, 19, '9')) return false;
      return true;
    case 5:
      if( DecodeSpecialChord( 5, 0, "println();", "print( \'{:s} {:.3f}\'.format())", "print", 0, 0)) return false;
      if( DecodeBaseChord( 5, 1, '[')) return false;
      if( DecodeBaseChord( 5, 2, ']')) return false;
      if( DecodeRussianChord( 5, 4, '^', '&')) return false;
      if( DecodeStringChord( 5, 5, ";", 0, 1)) return false;
      if( DecodeStringChord( 5, 6, "ph", 0, 0)) return false;
      if( DecodePlainStringChord( 5, 14, "try:except:", 7, 1)) return false;
      return true;
    case 6:
      if( DecodeRussianChord( 6, 1, '(', '<')) return false;
      if( DecodeRussianChord( 6, 2, ')', '>')) return false;
      if( DecodeStringChord( 6, 3, "sh", 0, 0)) return false;
      if( DecodeRussianChord( 6, 6, '\'', '\'')) return false;
      if( DecodePlainStringChord( 6, 14, "for i in range( len()):", 3, 0)) return false;
      if( DecodePlainStringChord( 6, 15, "and", 0, 0)) return false;
      return true;
    case 7:
      if( DecodeBaseChord( 7, 1, '=')) return false;
      if( DecodeRussianChord( 7, 2, '@', '#')) return false;
      if( DecodeStringChord( 7, 3, "qu", 0, 0)) return false;
      if( DecodeRussianChord( 7, 4, '^', '&')) return false;
      if( DecodeStringChord( 7, 6, "ch", 0, 0)) return false;
      if( DecodeStringChord( 7, 7, "ck", 0, 0)) return false;
      if( DecodeStringChord( 7, 14, "print( )", 1, 0)) return false;
      return true;
    case 8:
      if( DecodeStringChord( 8, 15, "False", 0, 0)) return false;
      return true;
    case 11:
      if( DecodeStringChord( 11, 1, _MACRO_1, 0, 0)) return false;
      if( DecodeStringChord( 11, 2, _MACRO_2, 0, 0)) return false;
      if( DecodeStringChord( 11, 3, _MACRO_3, 0, 0)) return false;
      if( DecodeStringChord( 11, 4, _MACRO_4, 0, 0)) return false;
      if( DecodeStringChord( 11, 5, _MACRO_5, 0, 0)) return false;
      if( DecodeStringChord( 11, 6, _MACRO_6, 0, 0)) return false;
      if( DecodeStringChord( 11, 7, _MACRO_7, 0, 0)) return false;
      if( DecodeStringChord( 11, 8, _MACRO_8, 0, 0)) return false;
      if( DecodeStringChord( 11, 9, _MACRO_9, 0, 0)) return false;
      if( DecodeStringChord( 11, 10, _MACRO_10, 0, 0)) return false;
      if( DecodeStringChord( 11, 11, _MACRO_11, 0, 0)) return false;
      if( DecodeStringChord( 11, 12, _MACRO_12, 0, 0)) return false;
      if( DecodeStringChord( 11, 13, _MACRO_13, 0, 0)) return false;
      if( DecodeStringChord( 11, 14, _MACRO_14, 0, 0)) return false;
      if( DecodeStringChord( 11, 15, _MACRO_15, 0, 0)) return false;
      return true;
    case 12:
      if( DecodePlainStringChord( 12, 1, "+", 0, 0)) return false;
      if( DecodePlainStringChord( 12, 2, "-", 0, 0)) return false;
      if( DecodePlainStringChord( 12, 3, "&", 0, 0)) return false;
      if( DecodePlainStringChord( 12, 4, "*", 0, 0)) return false;
      if( DecodePlainStringChord( 12, 6, "|", 0, 0)) return false;
      if( DecodePlainStringChord( 12, 7, "$", 0, 0)) return false;
      if( DecodePlainStringChord( 12, 8, "/", 0, 0)) return false;
      if( DecodeBaseChord( 12, 12, _ESC)) return false;
      return true;
    case 14:
      if( DecodePlainStringChord( 14, 1, "()", 1, 0)) return false;
      if( DecodePlainStringChord( 14, 2, "[]", 1, 0)) return false;
      if( DecodePlainStringChord( 14, 3, "<>", 1, 0)) return false;
      if( DecodePlainStringChord( 14, 4, "{}", 1, 0)) return false;
      if( DecodePlainStringChord( 14, 6, "\n{}", 1, 1)) return false;
      if( DecodeStringChord( 14, 8, "ou", 0, 0)) return false;
      if( DecodeStringChord( 14, 12, ":", 0, 1)) return false;
      if( DecodeStringChord( 14, 14, "the", 0, 0)) return false;
      return true;
    case 15:
      if( DecodePlainStringChord( 15, 1, "in", 0, 0)) return false;
      if( DecodeStringChord( 15, 2, "on", 0, 0)) return false;
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

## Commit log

2019-07-07 Version 9 of the keyboard sketch
    Compile directly with Arduino IDE.
2019-07-07 KiCAD files for PCBs
    [Center_Micro-B.Cu.gbr, Center_Micro-B.Mask.gbr, Center_Micro-B.SilkS.gbr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]
2019-07-07 Libraries used for kiCAD
2019-07-07 Stl files for printing or machining
    [Hackaday_Logo.stl, Joystick_Holder.stl, Joystick_Stand.stl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]
